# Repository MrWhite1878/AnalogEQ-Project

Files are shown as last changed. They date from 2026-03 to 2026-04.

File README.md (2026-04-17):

# AnalogEQ-Project
This repo serves to document relevant information on the design of an analog audio equalizer, whose goal is to serve as a learning tool and correctional component for my desktop speakers.
<!-- Photo -->
> WARNING: This project is a work in progress.
> Nothing is finalized, and this repo mainly serves to document and catalog my journey.

### Target Specifications
*	RCA audio input/output (adapters included)
*	9VAC Wall Wart power input
* ±18VDC rails powering NE5532 and TL072 op amps
* Smooth knobs for all controls
* High input impedance and low output impedance
* Audio bypass switch
* Input and Output Amplification
* 3rd order butterworth BPF for frequencies outside 20Hz-20kHz
* Sharp (Q = 10) -15dB Notch filter with adjustable target frequency (35-85Hz)
* LF and HF shelving with adjustable gain (±16dB) and proportional break/corner frequency
* 2 fully parametric middle controls: ±15dB gain, 70Hz-1.5kHz range 1 and 700-15kHz range 2, 0.5 < Q < 5
* Diagnostic board LEDs and testing pads

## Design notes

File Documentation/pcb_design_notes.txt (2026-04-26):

I learned KiCad and turned much of the simulation into a KiCad schematic with real components, footprints, MPNs, etc. I did not take any notes during this process, but I will include relevant information here.

Changes to be made: Notch bypass, i/o amplification, diagnostic (smd?) leds, testing pads, replacing/removing 1uF caps (maybe), smd resistors (maybe)

I want the final project to fit cleanly on my desk, in an enclosure. So, I planned for panel mount components (power, audio i/o, knobs). I plan to use JST-XH connectors for everything. I want a separate power board and signal board. I think about the size of notebook paper will do, so I'd like to keep the signal board within 200x100mm^2 and the power board within 100x50mm^2.

Rough estimate 11 pots with 2 switches 30mm center-to-center is about 400mm Panel width or with 2 rows I could get that down to 210*60mm^2 width*height. I like that and I can keep the board 

I decided on a definitive power solution. I do not want to juggle signal design with safety power design, so I will use a wall wart to step down the voltage from the wall to 12VAC. Then, I use a douglas design to double the voltage, rectify it, and pass it through LDOs. This produces extremely clean +-18V rails and avoids me having to worry about complicated power safety issues. The only problem is that with 43mA typ and 100mA max current draw from my op amp, I'll see significant drift from a standard wall wart (rated for about 1A), so I'll use a 9VAC wall wart.

Since this is a stereo circuit, I'll just use each side of the op amp since crosstalk is pretty low. Also thinking of having the component value inside the courtyard and the name outside of the courtyard.

Tried autorouting, kinda ugly. JLPCB has much better pricing than PCBWay based on testing. A little leeway in how I do it, but I should try to keep to standard stuff. TBH 2 Layer is cheaper but 4 layer might make cleaner routing isn;t much more expensive.

I need to find ways to integrate debugging pads and workarounds if something doesn't go well.

Components to buy that won't make it to the BOM:
Power
AC/AC Wall Wart - 77DA-12-09 by Ideal Power Ltd.
Panel Mount Barrel Jack - PJ-009AH by Same Sky
4x 100uF Caps - 

NOTE TO SELF:
You need to document which components you chose and why you chose them. Need to use chassis ground properly for components. Think about enclosure.

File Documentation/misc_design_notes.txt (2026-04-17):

EQ Design Notes

--
I want to design for:
-Bypass Switch for easy comparison/low noise
-Fixed freq HPF/LPF for speaker protection
-Fixed freq LF/HF shelving for broad tone control
-2 Fully parametric middle bands for specific controls
-Sweepable Notch filter for cleaning noise

This exposes me to many different filter designs while being highly functional
--- 
Goal is low resistance, linear, single gang pots. Avoid rotary switches ($5-$10).
Note that compromises made on freq range selection, as changing C in 1/2piRC only shifts the line up and down, not slope freq vs R loglog graphs.
--
Pre-amp not needed because the speakers will handle volume control. 
--
E24 values preferred for components since easier find and I have E24 metal film resistors. E6 caps though. I want metal film resistors default. X5R/X7R caps for decoupling, C0G(NP0) or Polypropylene (>1nF) caps for filters. 1kohm - 4.7kohm seems to be commonplace in audio design, due to balance noise, current, and parasitics. Try to keep cap values below 1u. Otherwise, consider bipolar electrolytic bypassed with PP film.

resistor noise prop. to  sqrt(R)

On decoupling. 100nF close to package across supply rails for NE5532/TL072, not two going to ground to avoid noise.

NE5532P default, solid option at a cheap price (5534 is x2, lm4562 x12). Input current bias on the NE5532 is 200-1000nA, 65-7000pA on the TL072, based on typical at 25C to full range temp. This becomes a problem with bigger resistors (do voltage/current noise calculations), so switch to the TL072 around 20kohm. TL072H might be best bc EMI filters, slew rate, and low power. TL072A/B have tighter input offset voltage. Right now TL072BCP seems to be best bang for buck.
---

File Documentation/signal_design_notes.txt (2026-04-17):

*These are some notes I made to myself while simulating the signal processing circuits in LTspice. I added in a few things I learned during PCB design. Note this was before I made the decision to switch to stereo.*

Sallen-Key vs. MFB
sallen-key is non inverting, but comes back up high freq. sallen-key HPF, MFB LPF.

Sallen-key HPF
Goal is speaker protection and power reduction, not tone shaping. These are corrective devices like the notch. In modern systems, typically used for power reduction of sub bass freq and EMI removal. Don't want audio distortion, so cutoff freq will probably be beyond 20Hz/20kHz. Need butterworth for cleaner rolloff and phase shift isn't significant.

Equal components vs unity gain. Probably unity gain for less distortion.
Unity gain can be scaled with a and b, note this is from Wikipedia not the book.
Maximize C1 and C2, but hard limit at 1u for price reasons. sets R1 and R2.
Optimized for about -1dB at 20Hz, which shouldn't have a noticeable effect on audio. But, it will attenuate low freq signals.

2nd,3rd,4th order. 2nd order is minimal design, typical. 3rd order only uses 1 more cap and 1 more resistor, not expensive. 4th order needs many more parts, and removes the possibility of a combined LPF/HPF. Potentially need to use TL072 on both stages? More parts means more noise. However, higher orders allow for attenuation. 3rd order filter makes sense to me. 1uF PP caps are massive though

MFB LPF

After some hiccups and a lot of math, 3rd order MFB inspired by the 3rd order sallen-key created. Solves all the issues with the sallen-key at HF. But this is best suited with a NE5532, so I may not be able to combine this with the HPF. Perhaps I'll find another stage to combine it with. 

---
Shelving

two cap version better for correction than one cap version. I'm not picky about phase shift, and I think having an appropriate break is more important for LF than HF. Doing double cap configurations on both actually set 3dB freq I was happy with compared to what originally in the book. This is another inverting topology. 10K is not enough noise for me to try to adjust for low impedance issues. Freq shifts with cut/gain which is very nice.

I should consider a switchable version of this with a middle control. Doesnt even have to be fully parametric
---
There's a lot of options for MIddle controls, probably because you can do some summing magic with bandpass filters. As a correctional device, I'm not interested in fixed freq devices. Wein network looks appealing for only using 1 op amp. Considering upgrading to stereo if I can get these designs to work. I'll have to decide how much I value the Q controllability to decide if I want fixed Q, switched Q, or fully variable Q. Compare my current bell to the book version. I like my fully parametric version, but I need to limit the ranges to 100-1k and 1k-10k so I can use smaller pots. Less noise and I can use the NE5532. Nvm main is a gain Q coupled circuit. Slightly modified Self's version (made R4 1K, lower impedance for more gain). This is good but the circuit is so sensitive to the gain/cut pos at the ends of the circuit. No idea how to fix tbh, even a buffer between the pot and r4 didn't do a ton. prolly need a lot of math to fix this.
---
Notch

to get a tunable notch we can use the bridged differentiator in 6.10d. consider the boctor, inverted svf. Adjusted R5 for a sharper Q (10) with less cut (-27dB to -15dB) because it will make it less audible. No phase shift so I can use a bypass switch for when it's off. Shifted caps from douglas to shift freq ranges to 35-85 for better room control 
---
Combined

There will both a bypass switch from input to output and a bypass across the notch. Have to use 2 channel op amps, so 2x NE5532, 4x TL072 = 52mA max draw? According to spice expecting a -90dB SNR

 Considering a new power supply. Added input output buffers. I should also add clipping detectors, LEDs on bypass switches, rubber feet. Reconsider max/min gain / "Master gain control" or "Input attenuator", consider power indicator and enclosure markings. Probably waterslide decals.

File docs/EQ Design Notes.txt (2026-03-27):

EQ Design Notes

--
I want to design for:
-Bypass Switch for easy comparison/low noise
-Fixed freq HPF/LPF for speaker protection
-Fixed freq LF/HF shelving for broad tone control
-2 Fully parametric middle bands for specific controls
-Sweepable Notch filter for cleaning noise

This exposes me to many different filter designs while being highly functional
---
Power: This should only be used when it's near outlets, so it makes sense to have some sort of wall wart, clean up or modify the signal, and make power rails. 15dB is standard max boost. 15dB = 5.62x, so ±15V rails = ±13V output = 2.3V peak input. Seems reasonable. Batteries seems inconvenient and bulk, USB voltage levels considered, but I'm worried about signal integrity, noise, power drain, etc. Not interested in designing power solution right now. Ne5532 draws 8mA max per channel and the TL072B draws 2.5mA max per channel. Likely need a 1W supply.
--
Goal is low resistance, linear, single gang pots. Avoid rotary switches ($5-$10).
Note that compromises made on freq range selection, as changing C in 1/2piRC only shifts the line up and down, not slope freq vs R loglog graphs.
--
Pre-amp not needed because the speakers will handle volume control. 
--
E24 values preferred for components since easier find and I have E24 metal film resistors. E6 caps though. I want metal film resistors default. X5R/X7R caps for decoupling, C0G(NP0) or Polypropylene (>1nF) caps for filters. 1kohm - 4.7kohm seems to be commonplace in audio design, due to balance noise, current, and parasitics. Try to keep cap values below 1u. Otherwise, consider bipolar electrolytic bypassed with PP film.

resistor noise prop. to  sqrt(R)

On decoupling. 100nF close to package across supply rails for NE5532/TL072, not two going to ground to avoid noise.

NE5532P default, solid option at a cheap price (5534 is x2, lm4562 x12). Input current bias on the NE5532 is 200-1000nA, 65-7000pA on the TL072, based on typical at 25C to full range temp. This becomes a problem with bigger resistors (do voltage/current noise calculations), so switch to the TL072 around 20kohm. TL072H might be best bc EMI filters, slew rate, and low power. TL072A/B have tighter input offset voltage. Right now TL072BCP seems to be best bang for buck.
---

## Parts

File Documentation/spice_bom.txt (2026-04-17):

2x NE5532
4x TL072
2x Bypass switch
Power

HPF
3x 1uF
1x 3kΩ
1x 7.5kΩ
1x 51kΩ

LPF
2x 10nF
1x 680pF
1x 1.1kΩ
1x 1.2kΩ
1x 2.7kΩ
1x 3.9kΩ

Notch
3x 220nF
1x 100kΩ
1x 39kΩ
1x 1kΩ
1x 12kΩ
1x 10kΩ pot LOG A
1x 100Ω
1x 10kΩ

Shelf
2x 100nF
2x 15nF
2x 10kΩ pot LIN B
2x 1.8kΩ
3x 1kΩ
1x 12kΩ

Middle1
1x 10nF
1x 47nF
1x 10kΩ pot LIN B
1x 100kΩ pot RLOG C
1x 100kΩ pot RLOG C 2GANG
1x 470Ω
1x 1kΩ
2x 2.2kΩ
4x 4.7kΩ
2x 6.8kΩ
2x 12kΩ
1x 100kΩ

Middle 2 (same, except caps)
1x 1nF
1x 4.7nF

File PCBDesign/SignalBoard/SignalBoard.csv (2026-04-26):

Qty | Value | Manufacturer | MPN | Digikey PN
2 | 680p | YAGEO | CC1206JRNPOYBN681 | 13-CC1206JRNPOYBN681CT-ND
2 | 1n | YAGEO | CC1206JRNPOBBN102 | 13-CC1206JRNPOBBN102CT-ND
2 | 4n7 | YAGEO | CC1206JRNPO0BN472 | 311-4403-1-ND
6 | 10n | YAGEO | CC1206JKNPO0BN103 | 311-4374-1-ND
4 | 15n | KEMET | PHE426DJ5150JR05
2 | 47n | KEMET | PHE426DJ5470JR05
2 | 100n | Vishay Beyschlag/Draloric/BC Components | K104K10X7RF53L2
14 | 100n | Samsung Electro-Mechanics | CL21B104KCFNNNE | 1276-6840-1-ND
4 | 100n | KEMET | PHE426HJ6100JR05
6 | 220n | KEMET | PHE426HA6220JR05
6 | 1u | Panasonic Industry | ECW-FE2W105JA
2 | 100u | Rubycon | 50ZLJ100M8X11.5
4 | 470u | Rubycon | 50ZLJ470M10X20
4 | 10K LIN | Bourns Inc. | PTD902-2215K-B103
1 | 10K LOG | Bourns Inc. | PDB182-K415K-103A1
2 | 47R | YAGEO | RT1206FRE0747RL | 13-RT1206FRE0747RLCT-ND
2 | 100 | YAGEO | RT1206DRD07100RL | 311-2915-1-ND
2 | 100K RLOG | Bourns Inc. | PTD902-2015K-C104
2 | 100K RLOG | Bourns Inc. | PTD904-2015K-C104
4 | 470R | YAGEO | RT1206DRE07470RL | 311-2995-1-ND
12 | 1K | YAGEO | RT1206DRD071KL | 311-2925-1-ND
4 | 1K1 | YAGEO | RT1206FRE071K1L | 13-RT1206FRE071K1LCT-ND
2 | 1K2 | YAGEO | RT1206FRE071K2L | 13-RT1206FRE071K2LCT-ND
4 | 1K8 | YAGEO | RT1206FRE071K8L | 13-RT1206FRE071K8LCT-ND
8 | 2K2 | YAGEO | RT1206DRE072K2L | 311-2984-1-ND
2 | 2K7 | YAGEO | RT1206DRE072K7L | 311-2985-1-ND
2 | 3K | YAGEO | RT1206DRD073KL | 13-RT1206DRD073KLCT-ND
16 | 4K7 | YAGEO | RT1206DRD074K7L | 13-RT1206DRD074K7LCT-ND
8 | 6K8 | YAGEO | RT1206DRD076K8L | 13-RT1206DRD076K8LCT-ND
2 | 7K5 | YAGEO | RT1206FRE077K5L | 13-RT1206FRE077K5LCT-ND
2 | 10K | YAGEO | RT1206DRD0710KL | 311-2916-1-ND
12 | 12K | YAGEO | RT1206DRE0712KL | 311-2960-1-ND
2 | 39K | YAGEO | RT1206DRE0739KL | 311-2991-1-ND
2 | 51K | YAGEO | RT1206DRD0751KL | 13-RT1206DRD0751KLCT-ND
2 | 100K | YAGEO | RT1206DRD07100KL | 311-2914-1-ND
2 | 220K | YAGEO | RT1206FRE07220KL | 13-RT1206FRE07220KLCT-ND
1 | T1A | Bel Fuse Inc. | 0697H1000-02 | 5923-0697H1000-02CT-ND
4 | 1N4004 | onsemi | 1N4004G | 1N4004GOS-ND
1 | ACAC_Wall_Wart | Ideal Power Ltd. | 77DA-12-09
1 | Barrel_Jack_Switch | Tensility International Corp | 54-00127
1 | LM7818_TO220 | onsemi | MC7818CTG
1 | LM7918_TO220 | onsemi | MC7918CTG
5 | NE5532 | Texas Instruments | NE5532P
1 | RCA_IN_L | Kycon, Inc. | KLPX-0848A-2-W
1 | RCA_IN_R | Kycon, Inc. | KLPX-0848A-2-R
1 | RCA_OUT_L | Kycon, Inc. | KLPX-0848A-2-W
1 | RCA_OUT_R | Kycon, Inc. | KLPX-0848A-2-R
2 | SW_4PDT_separate | E-Switch | 1004P1T1B9M7QEH
9 | TL072 | Texas Instruments | TL072BCP

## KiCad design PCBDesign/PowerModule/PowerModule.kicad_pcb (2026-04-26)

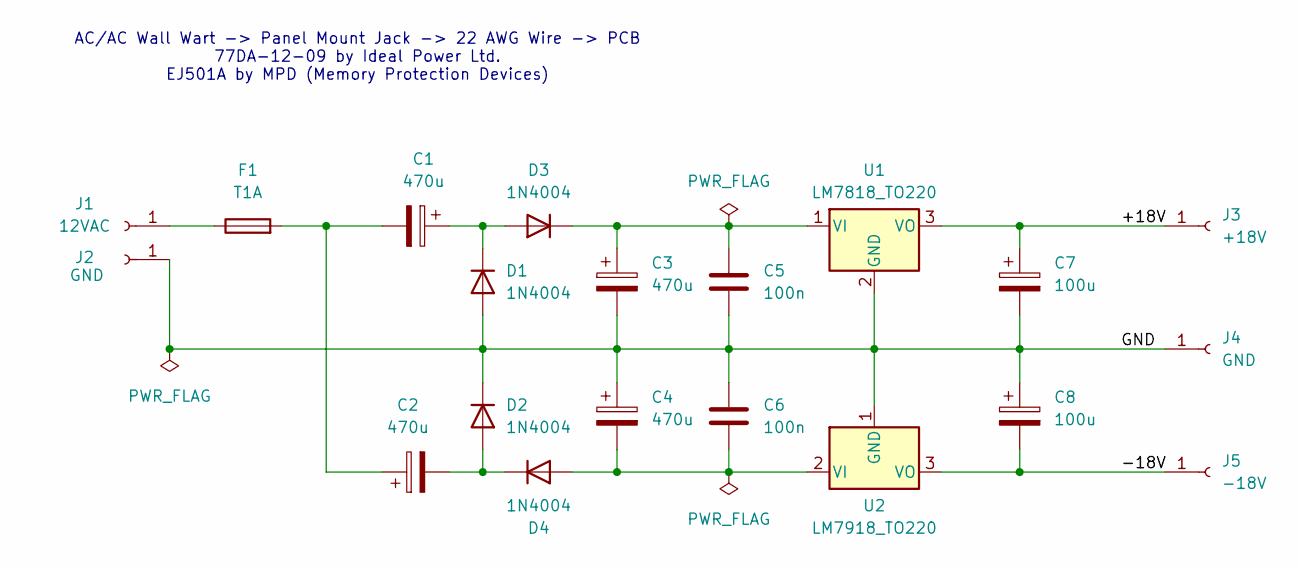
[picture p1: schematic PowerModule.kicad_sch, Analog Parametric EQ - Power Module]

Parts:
C1, C2, C3, C4: 470u; CP_Radial_D10.0mm_P5.00mm; MPN 50ZLJ470M10X20
C5, C6: 100n; C_Disc_D3.8mm_W2.6mm_P2.50mm; MPN K104K10X7RF53L2
C7, C8: 100u; CP_Radial_D8.0mm_P3.50mm; MPN 50ZLJ100M8X11.5
D1, D2, D3, D4: 1N4004; D_DO-41_SOD81_P10.16mm_Horizontal; MPN 1N4004G
F1: T1A; Fuse_BelFuse_0697H; MPN 0697H1000-02
J1: 12VAC; SolderWire-0.5sqmm_1x01_D0.9mm_OD2.1mm_Relief
J2, J4: GND; SolderWire-0.5sqmm_1x01_D0.9mm_OD2.1mm_Relief
J3: +18V; SolderWire-0.5sqmm_1x01_D0.9mm_OD2.1mm_Relief
J5: -18V; SolderWire-0.5sqmm_1x01_D0.9mm_OD2.1mm_Relief
U1: LM7818_TO220; TO-220-3_Vertical; MPN MC7818CTG
U2: LM7918_TO220; TO-220-3_Vertical; MPN MC7918CTG

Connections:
/+18V: C7.1, J3.1 (Pin_1_1), U1.3 (VO)
/-18V: C8.2, J5.1 (Pin_1_1), U2.3 (VO)
/GND: C3.2, C4.1, C5.2, C6.1, C7.2, C8.1, D1.2 (A), D2.1 (K), J2.1 (Pin_1_1), J4.1 (Pin_1_1), U1.2 (GND), U2.1 (GND)
unnamed: C1.2, C2.1, F1.2
unnamed: C1.1, D1.1 (K), D3.2 (A)
unnamed: C2.2, D2.2 (A), D4.1 (K)
unnamed: C3.1, C5.1, D3.1 (K), U1.1 (VI)
unnamed: C4.2, C6.2, D4.2 (A), U2.2 (VI)
unnamed: F1.1, J1.1 (Pin_1_1)

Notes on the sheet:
AC/AC Wall Wart -> Panel Mount Jack -> 22 AWG Wire -> PCB 77DA-12-09 by Ideal Power Ltd. EJ501A by MPD (Memory Protection Devices)

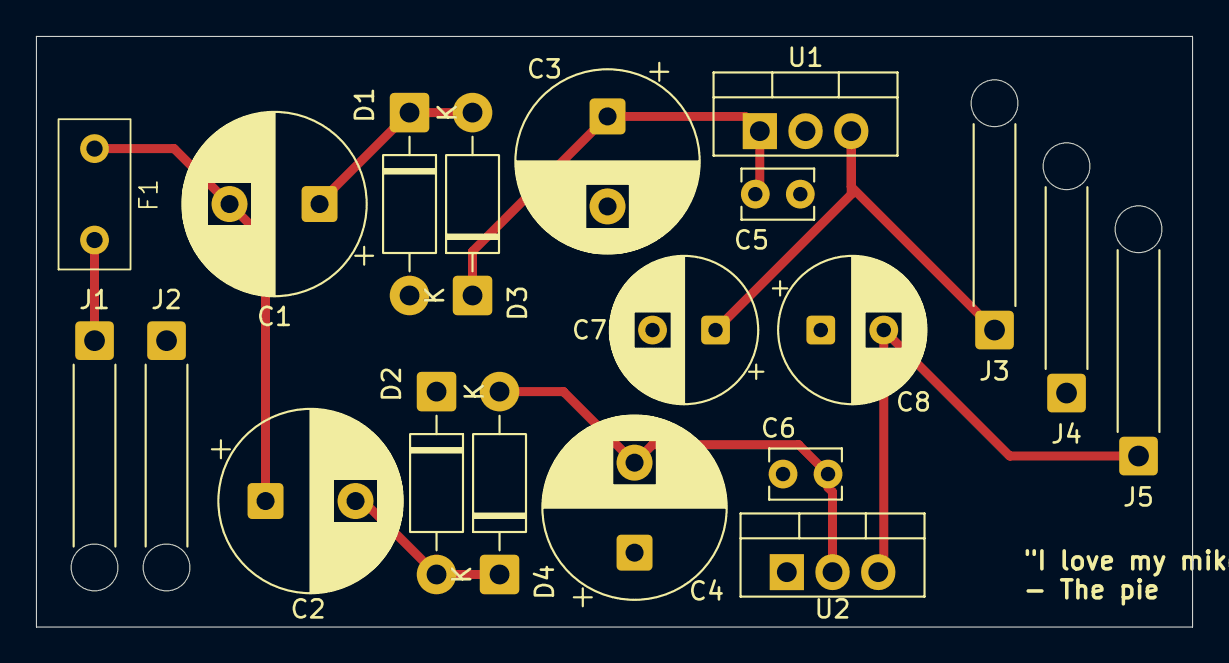
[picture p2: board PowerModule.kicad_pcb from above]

Board: 2 copper layers, 64.2 x 32.8 mm, 20 parts (0 on the bottom side), 9 nets.

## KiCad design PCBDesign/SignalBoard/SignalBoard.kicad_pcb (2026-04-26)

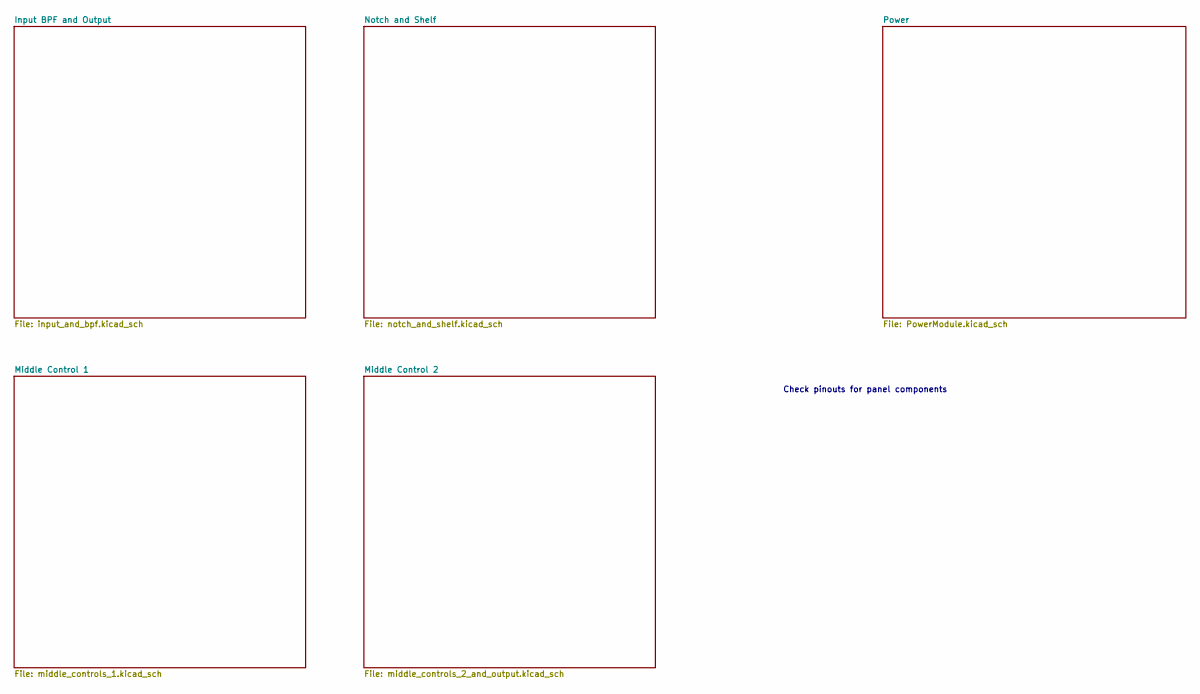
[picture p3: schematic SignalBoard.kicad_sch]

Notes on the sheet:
Check pinouts for panel components

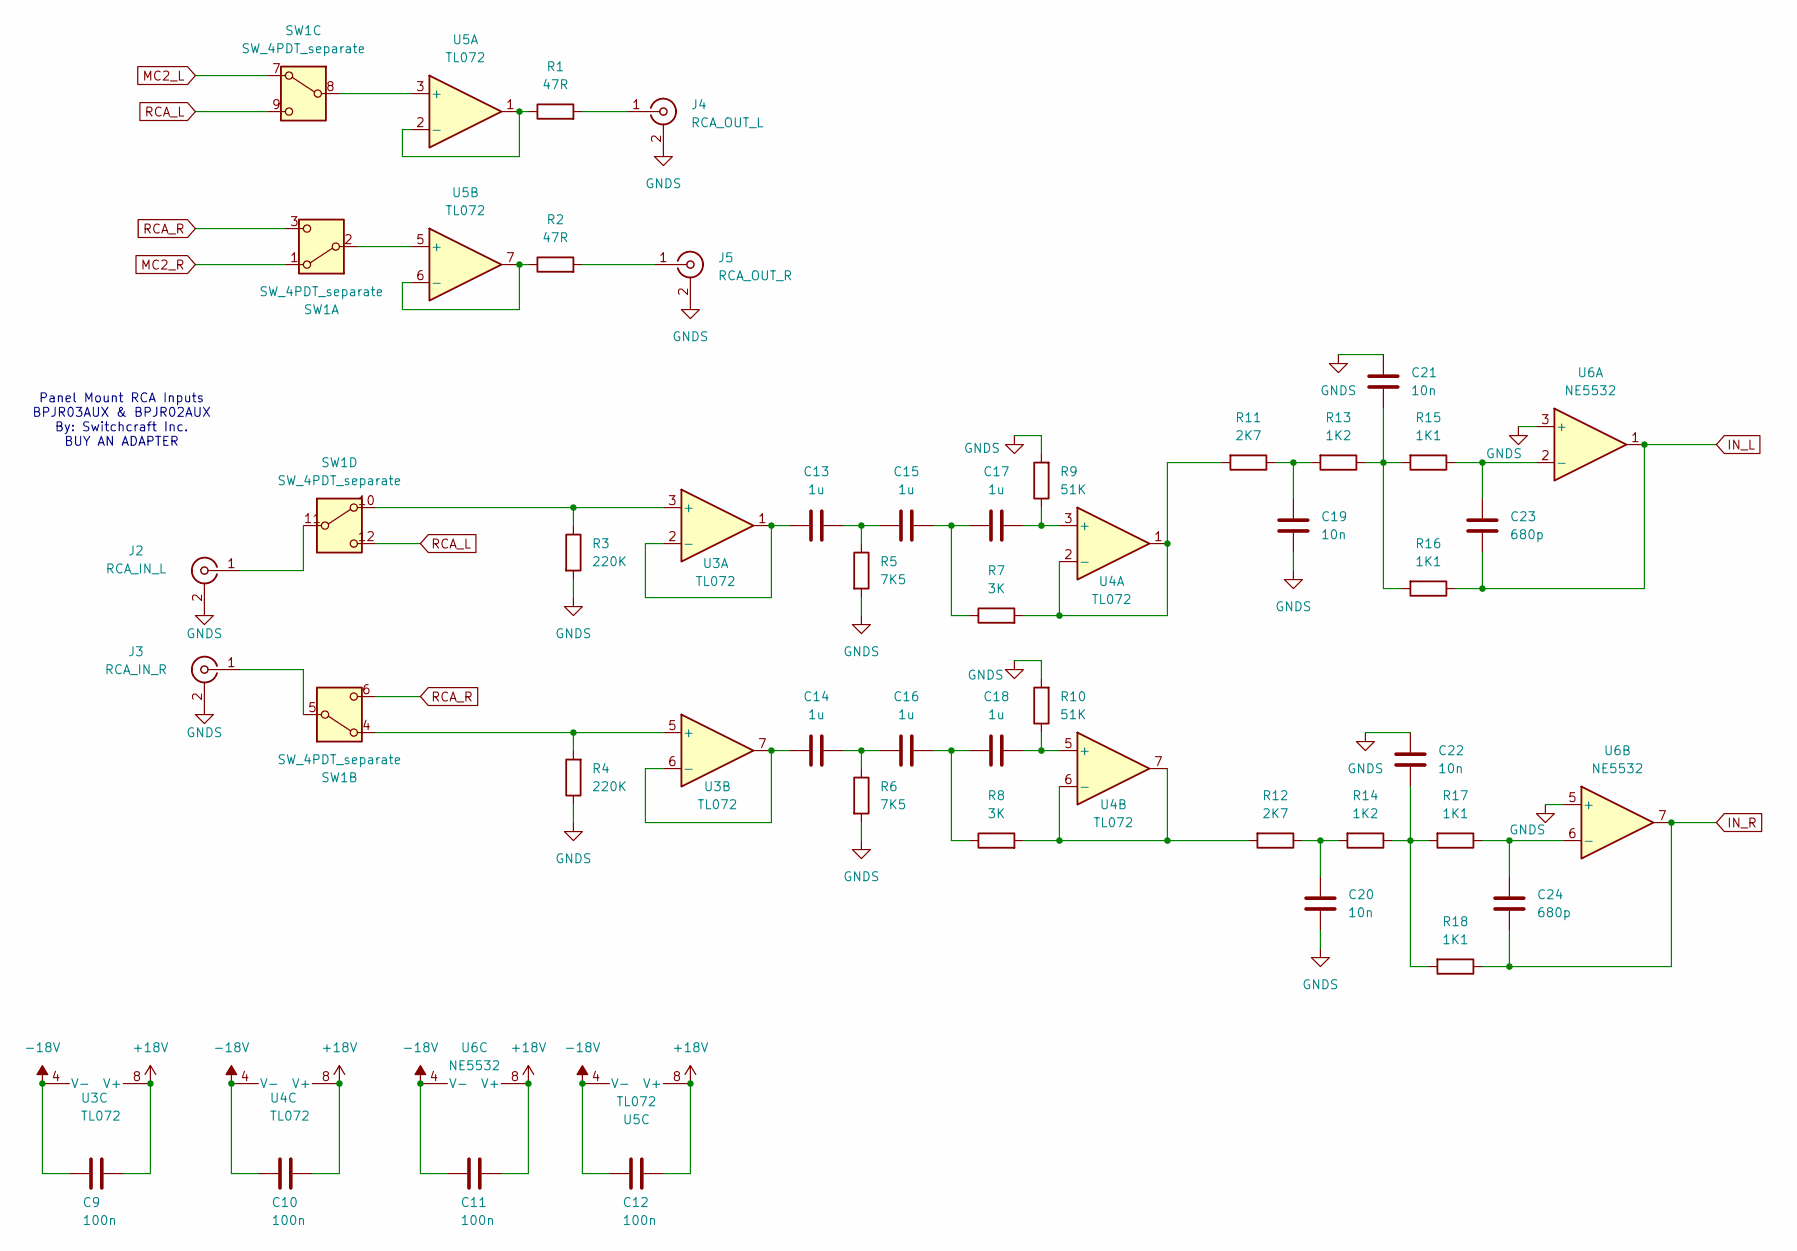
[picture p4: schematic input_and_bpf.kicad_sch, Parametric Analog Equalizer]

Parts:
C9, C10, C11, C12: 100n; C_0805_2012Metric_Pad1.18x1.45mm_HandSolder; MPN CL21B104KCFNNNE; Digikey PN 1276-6840-1-ND
C13, C14, C15, C16, C17, C18: 1u; C_Rect_L18.0mm_W7.0mm_P15.00mm_FKS3_FKP3; MPN ECW-FE2W105JA
C19, C20, C21, C22: 10n; C_1206_3216Metric_Pad1.33x1.80mm_HandSolder; MPN CC1206JKNPO0BN103; Digikey PN 311-4374-1-ND
C23, C24: 680p; C_1206_3216Metric_Pad1.33x1.80mm_HandSolder; MPN CC1206JRNPOYBN681; Digikey PN 13-CC1206JRNPOYBN681CT-ND
J2: RCA_IN_L; KLPX-0848A-2-; MPN KLPX-0848A-2-W
J3: RCA_IN_R; KLPX-0848A-2-; MPN KLPX-0848A-2-R
J4: RCA_OUT_L; KLPX-0848A-2-; MPN KLPX-0848A-2-W
J5: RCA_OUT_R; KLPX-0848A-2-; MPN KLPX-0848A-2-R
R1, R2: 47R; R_1206_3216Metric_Pad1.30x1.75mm_HandSolder; MPN RT1206FRE0747RL; Digikey PN 13-RT1206FRE0747RLCT-ND
R3, R4: 220K; R_1206_3216Metric_Pad1.30x1.75mm_HandSolder; MPN RT1206FRE07220KL; Digikey PN 13-RT1206FRE07220KLCT-ND
R5, R6: 7K5; R_1206_3216Metric_Pad1.30x1.75mm_HandSolder; MPN RT1206FRE077K5L; Digikey PN 13-RT1206FRE077K5LCT-ND
R7, R8: 3K; R_1206_3216Metric_Pad1.30x1.75mm_HandSolder; MPN RT1206DRD073KL; Digikey PN 13-RT1206DRD073KLCT-ND
R9, R10: 51K; R_1206_3216Metric_Pad1.30x1.75mm_HandSolder; MPN RT1206DRD0751KL; Digikey PN 13-RT1206DRD0751KLCT-ND
R11, R12: 2K7; R_1206_3216Metric_Pad1.30x1.75mm_HandSolder; MPN RT1206DRE072K7L; Digikey PN 311-2985-1-ND
R13, R14: 1K2; R_1206_3216Metric_Pad1.30x1.75mm_HandSolder; MPN RT1206FRE071K2L; Digikey PN 13-RT1206FRE071K2LCT-ND
R15, R16, R17, R18: 1K1; R_1206_3216Metric_Pad1.30x1.75mm_HandSolder; MPN RT1206FRE071K1L; Digikey PN 13-RT1206FRE071K1LCT-ND
SW1: SW_4PDT_separate; 1004P1T1B9M7QEH; MPN 1004P1T1B9M7QEH
U3, U4, U5: TL072; DIP-8_W7.62mm_LongPads; MPN TL072BCP
U6: NE5532; DIP-8_W7.62mm_LongPads; MPN NE5532P

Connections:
+18V: C9.1, C10.1, C11.1, C12.1, U3.8 (V+), U4.8 (V+), U5.8 (V+), U6.8 (V+); also elsewhere on the board
-18V: C9.2, C10.2, C11.2, C12.2, U3.4 (V-), U4.4 (V-), U5.4 (V-), U6.4 (V-); also elsewhere on the board
GNDS: C19.2, C20.2, C21.1, C22.1, J2.2 (Ext), J3.2 (Ext), J4.2 (Ext), J5.2 (Ext), R3.2, R4.1, R5.2, R6.2, R9.2, R10.2, U6.3 (+), U6.5 (+); also elsewhere on the board
IN_L: C23.2, R16.1, U6.1; also elsewhere on the board
IN_R: C24.2, R18.1, U6.7; also elsewhere on the board
MC2_L: SW1.7 (A); also elsewhere on the board
MC2_R: SW1.1 (A); also elsewhere on the board
unnamed: C13.2, C15.1, R5.1
unnamed: C14.2, C16.1, R6.1
unnamed: C15.2, C17.1, R7.1
unnamed: C16.2, C18.1, R8.1
unnamed: C19.1, R11.1, R13.2
unnamed: C20.1, R12.1, R14.2
unnamed: C21.2, R13.1, R15.2, R16.2
unnamed: C22.2, R14.1, R17.2, R18.2
unnamed: J2.1 (In), SW1.11 (B)
unnamed: J3.1 (In), SW1.5 (B)
unnamed: J4.1 (In), R1.2
unnamed: J5.1 (In), R2.2
unnamed: SW1.2 (B), U5.5 (+)
unnamed: R4.2, SW1.4 (A), U3.5 (+)
unnamed: SW1.8 (B), U5.3 (+)
unnamed: R3.1, SW1.10 (A), U3.3 (+)
unnamed: C13.1, U3.1, U3.2 (-)
unnamed: C14.1, U3.6 (-), U3.7
unnamed: C17.2, R9.1, U4.3 (+)
unnamed: R7.2, R11.2, U4.1, U4.2 (-)
unnamed: C18.2, R10.1, U4.5 (+)
unnamed: R8.2, R12.2, U4.6 (-), U4.7
unnamed: R1.1, U5.1, U5.2 (-)
unnamed: R2.1, U5.6 (-), U5.7
unnamed: C23.1, R15.1, U6.2 (-)
unnamed: C24.1, R17.1, U6.6 (-)
RCA_L: SW1.9 (C), SW1.12 (C)
RCA_R: SW1.3 (C), SW1.6 (C)

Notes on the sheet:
Panel Mount RCA Inputs BPJR03AUX & BPJR02AUX By: Switchcraft Inc. BUY AN ADAPTER

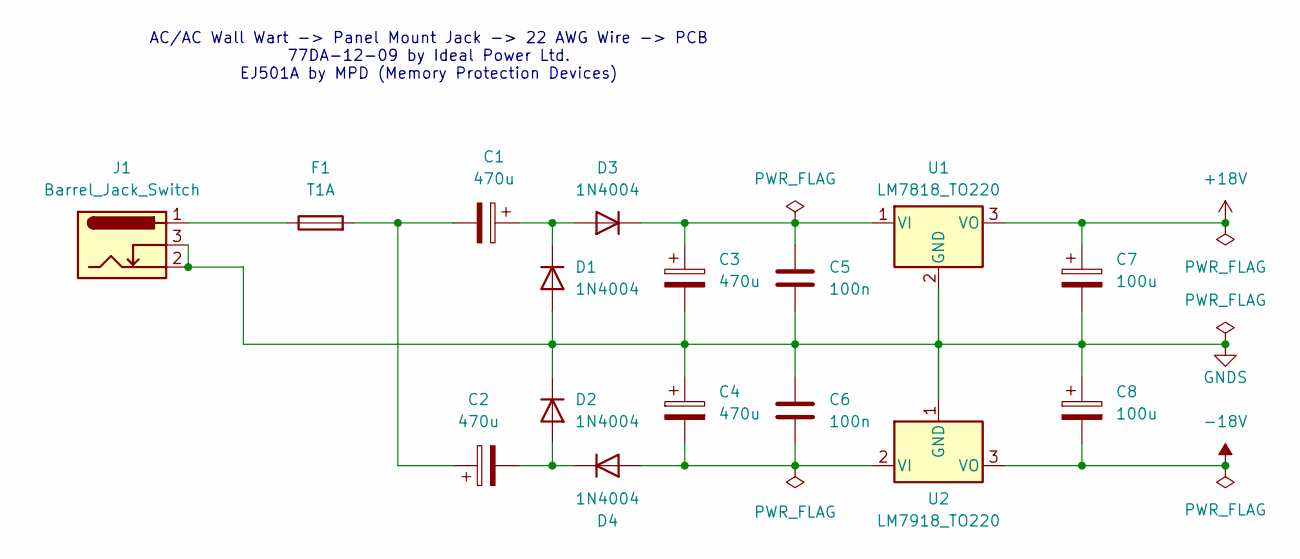
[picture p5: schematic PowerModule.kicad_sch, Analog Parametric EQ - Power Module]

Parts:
C1, C2, C3, C4: 470u; CP_Radial_D10.0mm_P5.00mm; MPN 50ZLJ470M10X20
C5, C6: 100n; C_Disc_D3.8mm_W2.6mm_P2.50mm; MPN K104K10X7RF53L2
C7, C8: 100u; CP_Radial_D8.0mm_P3.50mm; MPN 50ZLJ100M8X11.5
D1, D2, D3, D4: 1N4004; D_DO-41_SOD81_P10.16mm_Horizontal; MPN 1N4004G; Digikey PN 1N4004GOS-ND
F1: T1A; Fuse_BelFuse_0697H; MPN 0697H1000-02; Digikey PN 5923-0697H1000-02CT-ND
J1: Barrel_Jack_Switch; 54-00127; MPN 54-00127
U1: LM7818_TO220; TO-220-3_Vertical; MPN MC7818CTG
U2: LM7918_TO220; TO-220-3_Vertical; MPN MC7918CTG

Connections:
+18V: C7.1, U1.3 (VO); also elsewhere on the board
-18V: C8.2, U2.3 (VO); also elsewhere on the board
GNDS: C3.2, C4.1, C5.2, C6.1, C7.2, C8.1, D1.2 (A), D2.1 (K), J1.2, J1.3, U1.2 (GND), U2.1 (GND); also elsewhere on the board
unnamed: C1.2, C2.1, F1.2
unnamed: C1.1, D1.1 (K), D3.2 (A)
unnamed: C2.2, D2.2 (A), D4.1 (K)
unnamed: C3.1, C5.1, D3.1 (K), U1.1 (VI)
unnamed: C4.2, C6.2, D4.2 (A), U2.2 (VI)
unnamed: F1.1, J1.1

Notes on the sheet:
AC/AC Wall Wart -> Panel Mount Jack -> 22 AWG Wire -> PCB 77DA-12-09 by Ideal Power Ltd. EJ501A by MPD (Memory Protection Devices)

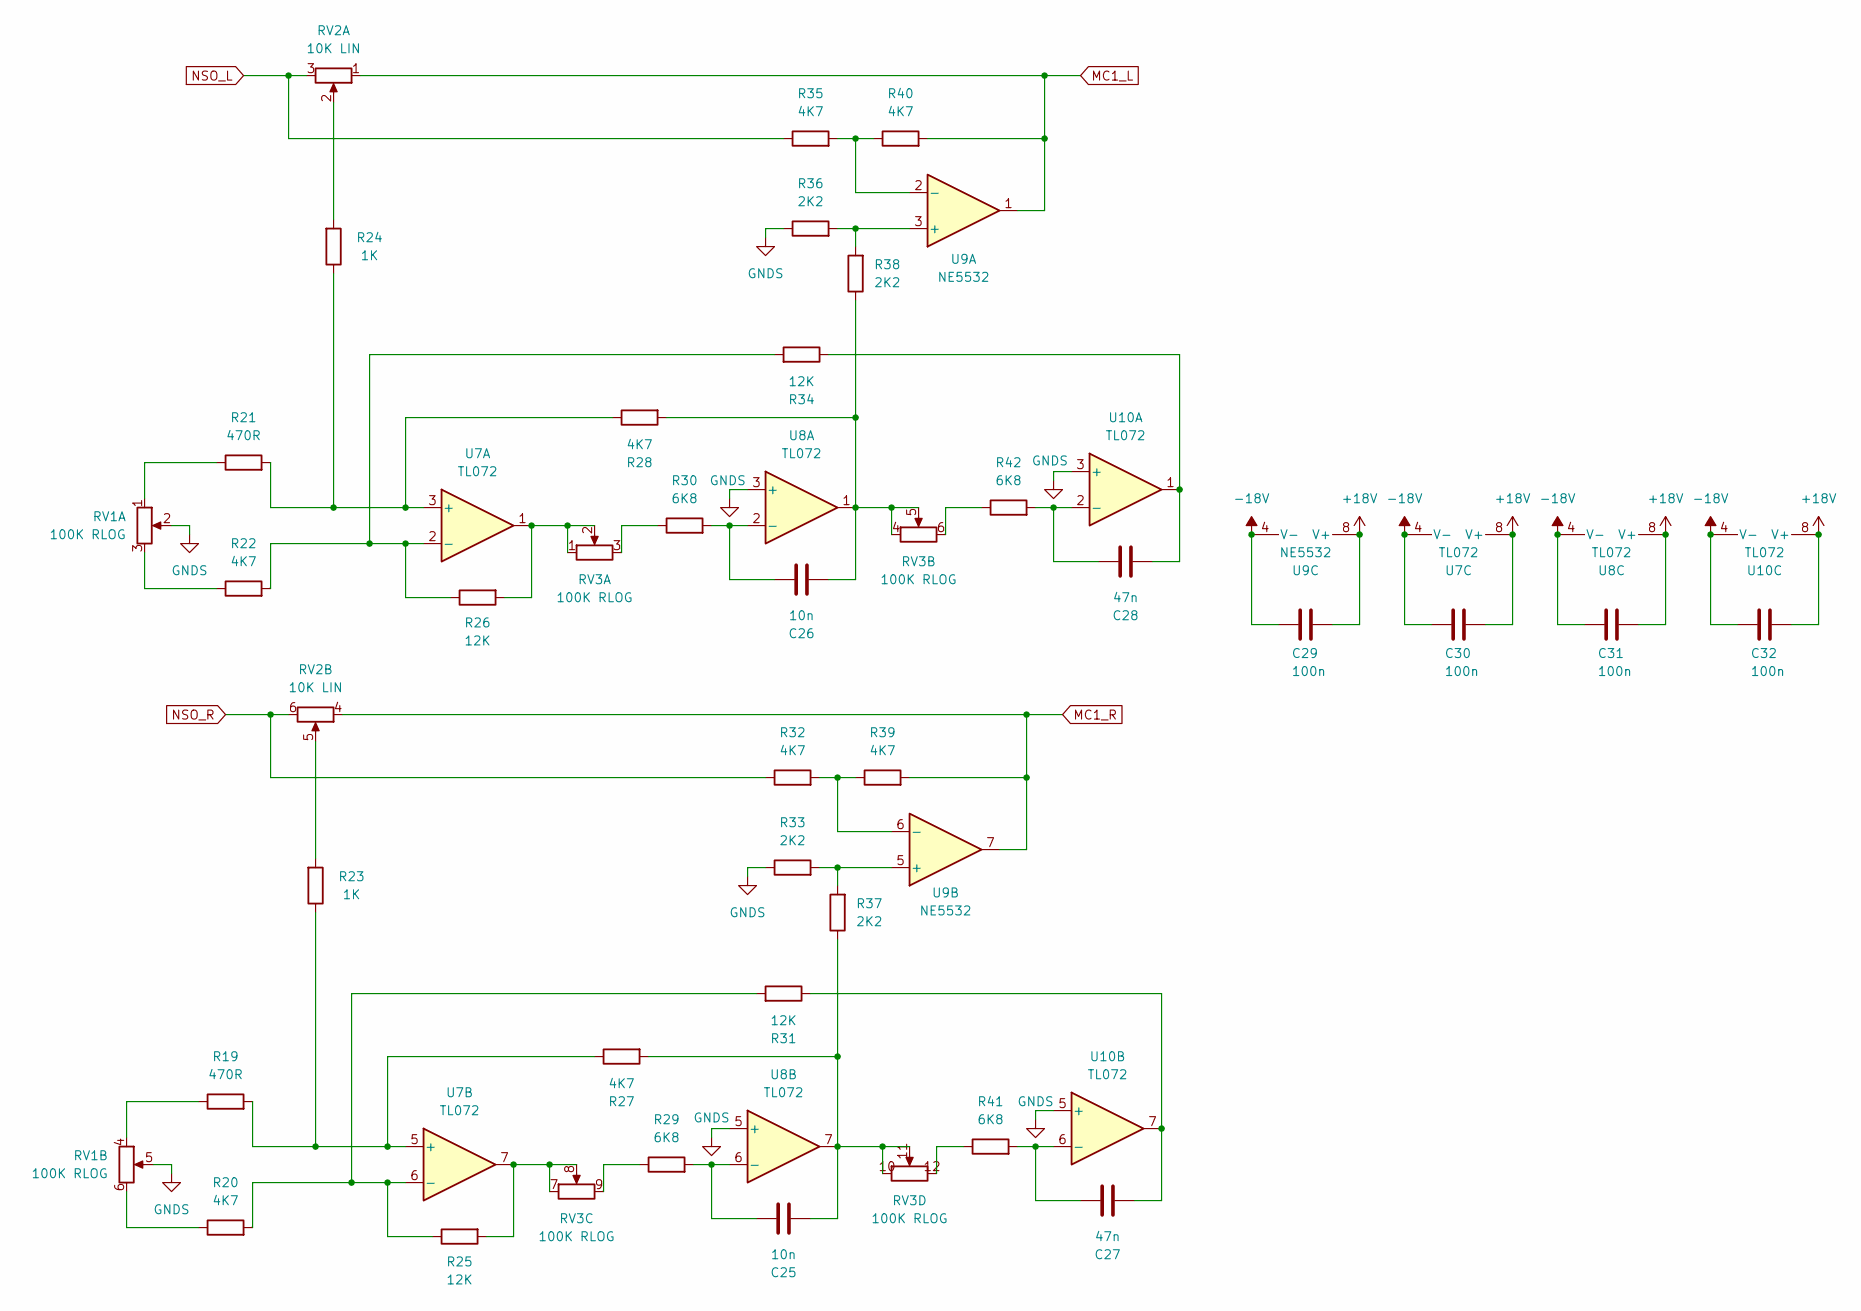
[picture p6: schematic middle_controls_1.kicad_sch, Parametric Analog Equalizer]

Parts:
C25, C26: 10n; C_1206_3216Metric_Pad1.33x1.80mm_HandSolder; MPN CC1206JKNPO0BN103; Digikey PN 311-4374-1-ND
C27, C28: 47n; C_Rect_L7.2mm_W3.5mm_P5.00mm_FKS2_FKP2_MKS2_MKP2; MPN PHE426DJ5470JR05
C29, C30, C31, C32: 100n; C_0805_2012Metric_Pad1.18x1.45mm_HandSolder; MPN CL21B104KCFNNNE; Digikey PN 1276-6840-1-ND
R19, R21: 470R; R_1206_3216Metric_Pad1.30x1.75mm_HandSolder; MPN RT1206DRE07470RL; Digikey PN 311-2995-1-ND
R20, R22, R27, R28, R32, R35, R39, R40: 4K7; R_1206_3216Metric_Pad1.30x1.75mm_HandSolder; MPN RT1206DRD074K7L; Digikey PN 13-RT1206DRD074K7LCT-ND
R23, R24: 1K; R_1206_3216Metric_Pad1.30x1.75mm_HandSolder; MPN RT1206DRD071KL; Digikey PN 311-2925-1-ND
R25, R26, R31, R34: 12K; R_1206_3216Metric_Pad1.30x1.75mm_HandSolder; MPN RT1206DRE0712KL; Digikey PN 311-2960-1-ND
R29, R30, R41, R42: 6K8; R_1206_3216Metric_Pad1.30x1.75mm_HandSolder; MPN RT1206DRD076K8L; Digikey PN 13-RT1206DRD076K8LCT-ND
R33, R36, R37, R38: 2K2; R_1206_3216Metric_Pad1.30x1.75mm_HandSolder; MPN RT1206DRE072K2L; Digikey PN 311-2984-1-ND
RV1: 100K RLOG; PTD902-2215K-B103; MPN PTD902-2015K-C104
RV2: 10K LIN; PTD902-2215K-B103; MPN PTD902-2215K-B103
RV3: 100K RLOG; PTD904-2015K-C104; MPN PTD904-2015K-C104
U7, U8, U10: TL072; DIP-8_W7.62mm_LongPads; MPN TL072BCP
U9: NE5532; DIP-8_W7.62mm_LongPads; MPN NE5532P

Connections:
+18V: C29.1, C30.1, C31.1, C32.1, U7.8 (V+), U8.8 (V+), U9.8 (V+), U10.8 (V+); also elsewhere on the board
-18V: C29.2, C30.2, C31.2, C32.2, U7.4 (V-), U8.4 (V-), U9.4 (V-), U10.4 (V-); also elsewhere on the board
GNDS: R33.1, R36.1, RV1.2, RV1.5, U8.3 (+), U8.5 (+), U10.3 (+), U10.5 (+); also elsewhere on the board
MC1_L: R40.2, RV2.1, U9.1; also elsewhere on the board
MC1_R: R39.2, RV2.4, U9.7; also elsewhere on the board
NSO_L: R35.1, RV2.3; also elsewhere on the board
NSO_R: R32.1, RV2.6; also elsewhere on the board
unnamed: C25.2, R27.2, R37.1, RV3.10, RV3.11, U8.7
unnamed: C26.2, R28.2, R38.1, RV3.4, RV3.5, U8.1
unnamed: C27.2, R31.1, U10.7
unnamed: C28.2, R34.1, U10.1
unnamed: R19.1, RV1.4
unnamed: R20.1, RV1.6
unnamed: R21.1, RV1.1
unnamed: R22.1, RV1.3
unnamed: R23.2, RV2.5
unnamed: R24.2, RV2.2
unnamed: R25.2, RV3.7, RV3.8, U7.7
unnamed: R26.2, RV3.1, RV3.2, U7.1
unnamed: R29.1, RV3.9
unnamed: R30.1, RV3.3
unnamed: R41.1, RV3.12
unnamed: R42.1, RV3.6
unnamed: R21.2, R24.1, R28.1, U7.3 (+)
unnamed: R22.2, R26.1, R34.2, U7.2 (-)
unnamed: R19.2, R23.1, R27.1, U7.5 (+)
unnamed: R20.2, R25.1, R31.2, U7.6 (-)
unnamed: C26.1, R30.2, U8.2 (-)
unnamed: C25.1, R29.2, U8.6 (-)
unnamed: R36.2, R38.2, U9.3 (+)
unnamed: R35.2, R40.1, U9.2 (-)
unnamed: R33.2, R37.2, U9.5 (+)
unnamed: R32.2, R39.1, U9.6 (-)
unnamed: C28.1, R42.2, U10.2 (-)
unnamed: C27.1, R41.2, U10.6 (-)

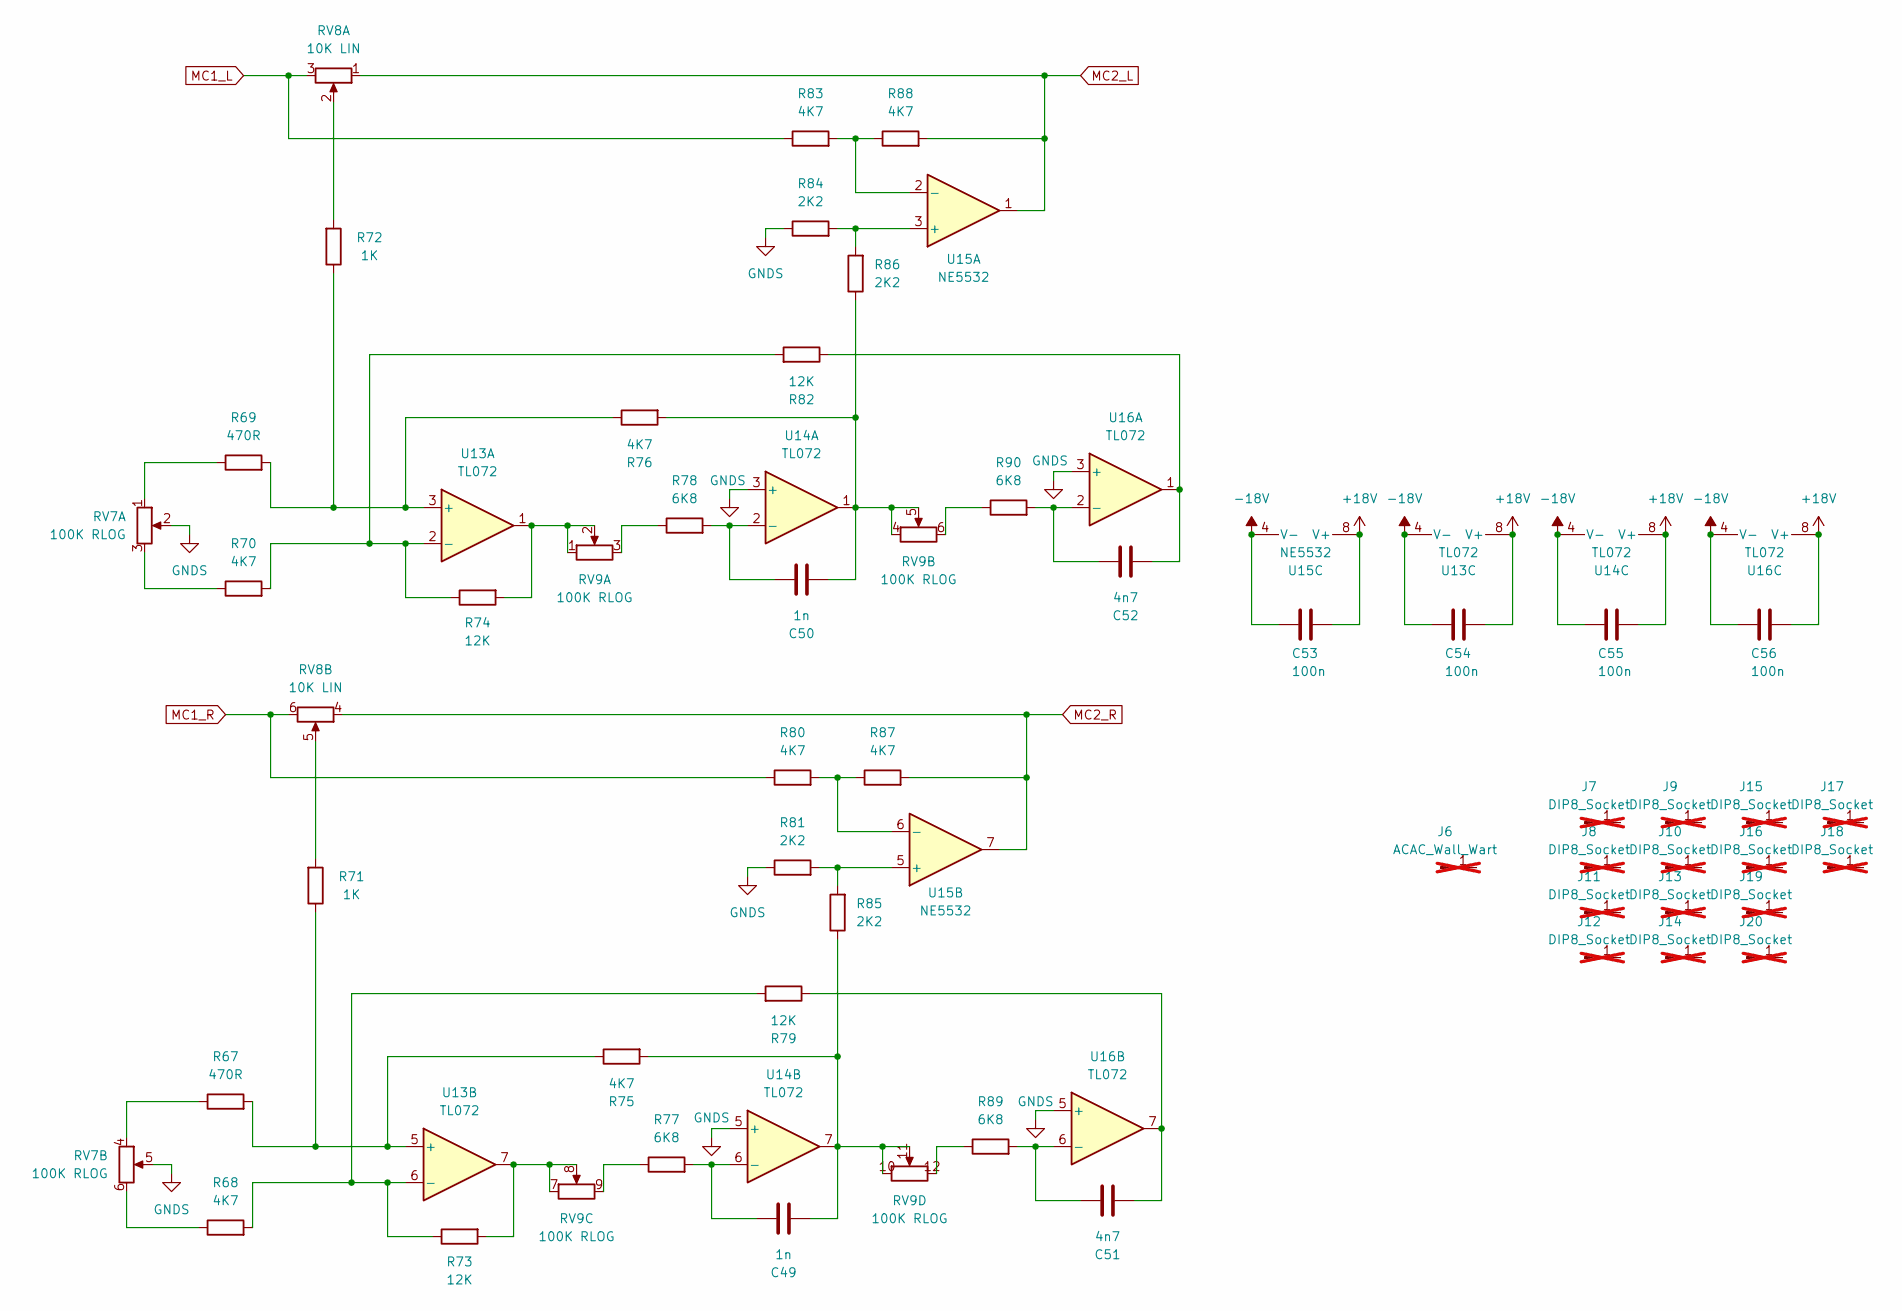
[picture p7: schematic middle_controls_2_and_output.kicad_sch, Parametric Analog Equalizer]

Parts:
C49, C50: 1n; C_1206_3216Metric_Pad1.33x1.80mm_HandSolder; MPN CC1206JRNPOBBN102; Digikey PN 13-CC1206JRNPOBBN102CT-ND
C51, C52: 4n7; C_1206_3216Metric_Pad1.33x1.80mm_HandSolder; MPN CC1206JRNPO0BN472; Digikey PN 311-4403-1-ND
C53, C54, C55, C56: 100n; C_0805_2012Metric_Pad1.18x1.45mm_HandSolder; MPN CL21B104KCFNNNE; Digikey PN 1276-6840-1-ND
J6: ACAC_Wall_Wart; MPN 77DA-12-09; not fitted
J7, J8, J9, J10, J11, J12, J13, J14, J15, J16, J17, J18, J19, J20: DIP8_Socket; MPN ICS-308-T; Digikey PN 2057-ICS-308-T-ND; not fitted
R67, R69: 470R; R_1206_3216Metric_Pad1.30x1.75mm_HandSolder; MPN RT1206DRE07470RL; Digikey PN 311-2995-1-ND
R68, R70, R75, R76, R80, R83, R87, R88: 4K7; R_1206_3216Metric_Pad1.30x1.75mm_HandSolder; MPN RT1206DRD074K7L; Digikey PN 13-RT1206DRD074K7LCT-ND
R71, R72: 1K; R_1206_3216Metric_Pad1.30x1.75mm_HandSolder; MPN RT1206DRD071KL; Digikey PN 311-2925-1-ND
R73, R74, R79, R82: 12K; R_1206_3216Metric_Pad1.30x1.75mm_HandSolder; MPN RT1206DRE0712KL; Digikey PN 311-2960-1-ND
R77, R78, R89, R90: 6K8; R_1206_3216Metric_Pad1.30x1.75mm_HandSolder; MPN RT1206DRD076K8L; Digikey PN 13-RT1206DRD076K8LCT-ND
R81, R84, R85, R86: 2K2; R_1206_3216Metric_Pad1.30x1.75mm_HandSolder; MPN RT1206DRE072K2L; Digikey PN 311-2984-1-ND
RV7: 100K RLOG; PTD902-2215K-B103; MPN PTD902-2015K-C104
RV8: 10K LIN; PTD902-2215K-B103; MPN PTD902-2215K-B103
RV9: 100K RLOG; PTD904-2015K-C104; MPN PTD904-2015K-C104
U13, U14, U16: TL072; DIP-8_W7.62mm_LongPads; MPN TL072BCP
U15: NE5532; DIP-8_W7.62mm_LongPads; MPN NE5532P

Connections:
+18V: C53.1, C54.1, C55.1, C56.1, U13.8 (V+), U14.8 (V+), U15.8 (V+), U16.8 (V+); also elsewhere on the board
-18V: C53.2, C54.2, C55.2, C56.2, U13.4 (V-), U14.4 (V-), U15.4 (V-), U16.4 (V-); also elsewhere on the board
GNDS: R81.1, R84.1, RV7.2, RV7.5, U14.3 (+), U14.5 (+), U16.3 (+), U16.5 (+); also elsewhere on the board
MC1_L: R83.1, RV8.3; also elsewhere on the board
MC1_R: R80.1, RV8.6; also elsewhere on the board
MC2_L: R88.2, RV8.1, U15.1; also elsewhere on the board
MC2_R: R87.2, RV8.4, U15.7; also elsewhere on the board
unnamed: C49.2, R75.2, R85.1, RV9.10, RV9.11, U14.7
unnamed: C50.2, R76.2, R86.1, RV9.4, RV9.5, U14.1
unnamed: C51.2, R79.1, U16.7
unnamed: C52.2, R82.1, U16.1
unnamed: R67.1, RV7.4
unnamed: R68.1, RV7.6
unnamed: R69.1, RV7.1
unnamed: R70.1, RV7.3
unnamed: R71.2, RV8.5
unnamed: R72.2, RV8.2
unnamed: R73.2, RV9.7, RV9.8, U13.7
unnamed: R74.2, RV9.1, RV9.2, U13.1
unnamed: R77.1, RV9.9
unnamed: R78.1, RV9.3
unnamed: R89.1, RV9.12
unnamed: R90.1, RV9.6
unnamed: R69.2, R72.1, R76.1, U13.3 (+)
unnamed: R70.2, R74.1, R82.2, U13.2 (-)
unnamed: R67.2, R71.1, R75.1, U13.5 (+)
unnamed: R68.2, R73.1, R79.2, U13.6 (-)
unnamed: C50.1, R78.2, U14.2 (-)
unnamed: C49.1, R77.2, U14.6 (-)
unnamed: R84.2, R86.2, U15.3 (+)
unnamed: R83.2, R88.1, U15.2 (-)
unnamed: R81.2, R85.2, U15.5 (+)
unnamed: R80.2, R87.1, U15.6 (-)
unnamed: C52.1, R90.2, U16.2 (-)
unnamed: C51.1, R89.2, U16.6 (-)

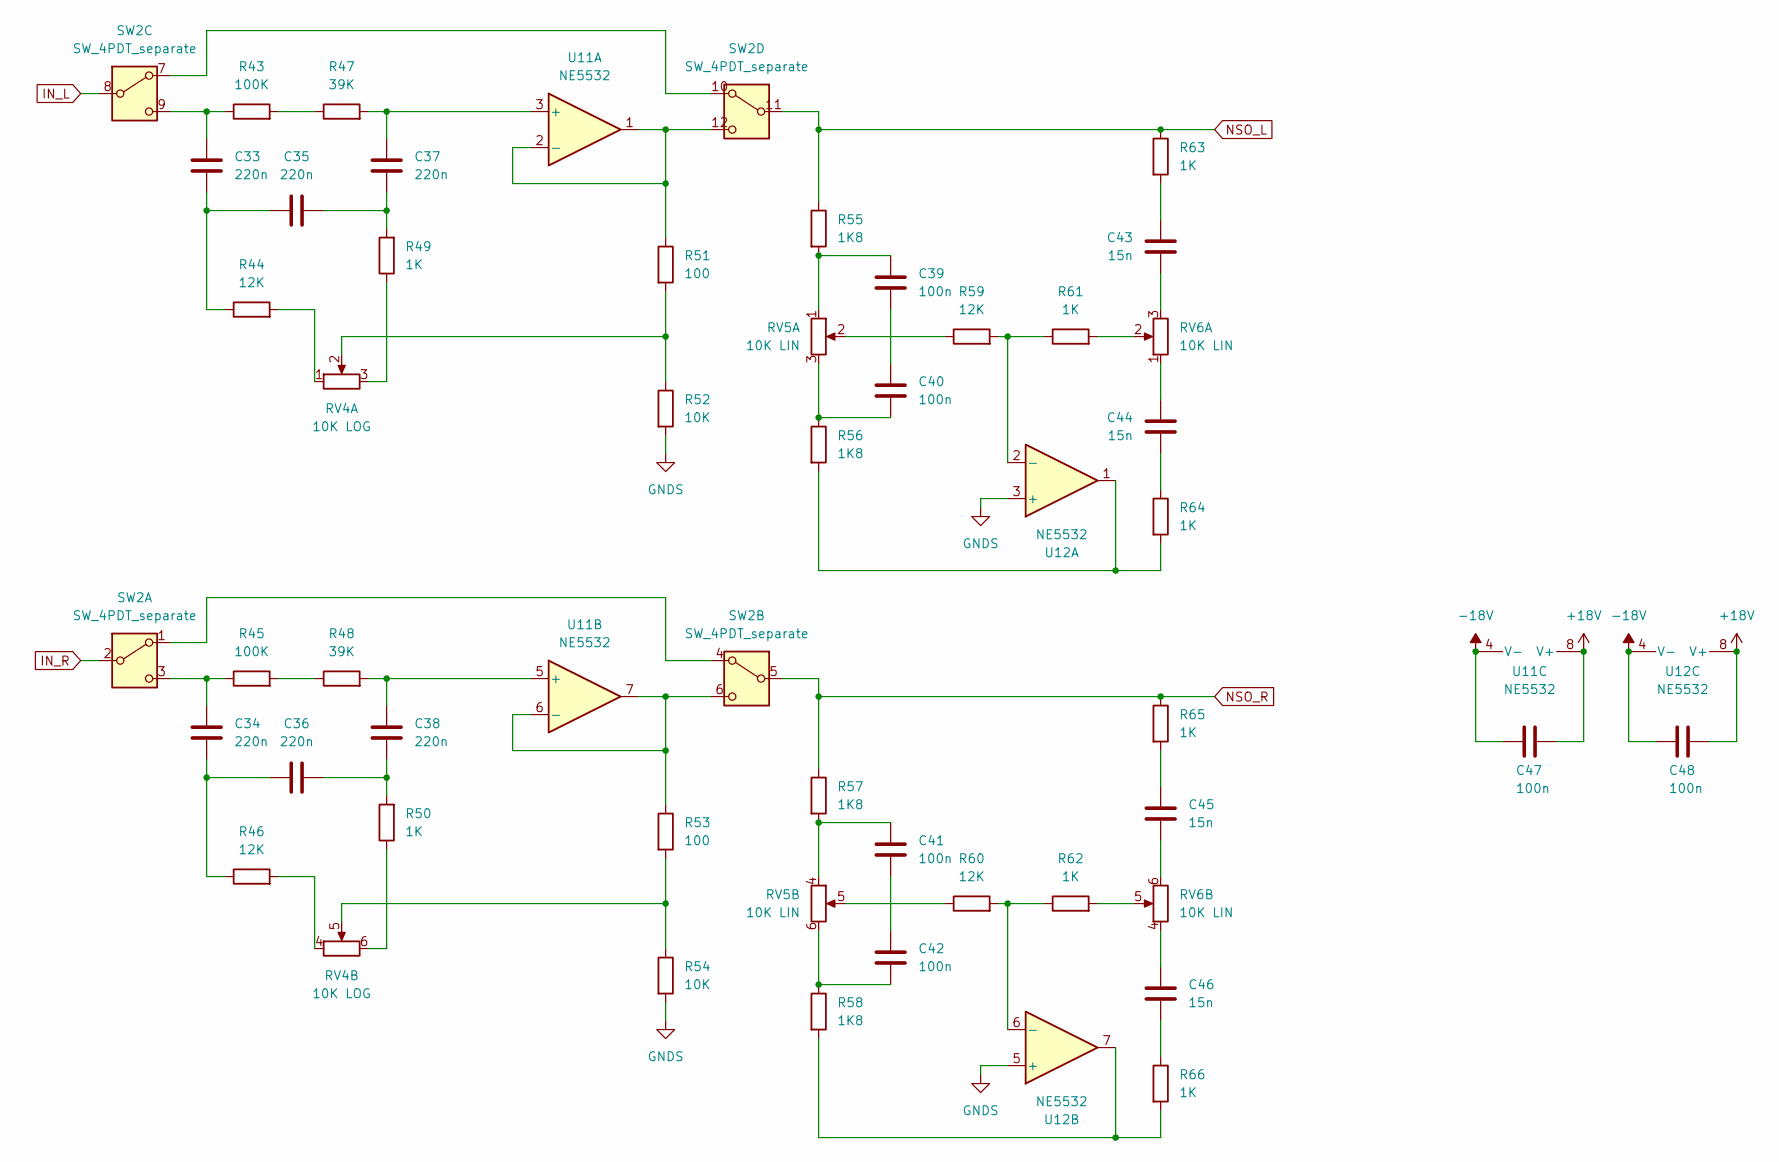
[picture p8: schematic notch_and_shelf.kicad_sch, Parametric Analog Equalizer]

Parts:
C33, C34, C35, C36, C37, C38: 220n; C_Rect_L13.0mm_W6.0mm_P10.00mm_FKS3_FKP3_MKS4; MPN PHE426HA6220JR05
C39, C40, C41, C42: 100n; C_Rect_L7.2mm_W6.0mm_P5.00mm; MPN PHE426HJ6100JR05
C43, C44, C45, C46: 15n; C_Rect_L7.2mm_W2.5mm_P5.00mm_FKS2_FKP2_MKS2_MKP2; MPN PHE426DJ5150JR05
C47, C48: 100n; C_0805_2012Metric_Pad1.18x1.45mm_HandSolder; MPN CL21B104KCFNNNE; Digikey PN 1276-6840-1-ND
R43, R45: 100K; R_1206_3216Metric_Pad1.30x1.75mm_HandSolder; MPN RT1206DRD07100KL; Digikey PN 311-2914-1-ND
R44, R46, R59, R60: 12K; R_1206_3216Metric_Pad1.30x1.75mm_HandSolder; MPN RT1206DRE0712KL; Digikey PN 311-2960-1-ND
R47, R48: 39K; R_1206_3216Metric_Pad1.30x1.75mm_HandSolder; MPN RT1206DRE0739KL; Digikey PN 311-2991-1-ND
R49, R50, R61, R62, R63, R64, R65, R66: 1K; R_1206_3216Metric_Pad1.30x1.75mm_HandSolder; MPN RT1206DRD071KL; Digikey PN 311-2925-1-ND
R51, R53: 100; R_1206_3216Metric_Pad1.30x1.75mm_HandSolder; MPN RT1206DRD07100RL; Digikey PN 311-2915-1-ND
R52, R54: 10K; R_1206_3216Metric_Pad1.30x1.75mm_HandSolder; MPN RT1206DRD0710KL; Digikey PN 311-2916-1-ND
R55, R56, R57, R58: 1K8; R_1206_3216Metric_Pad1.30x1.75mm_HandSolder; MPN RT1206FRE071K8L; Digikey PN 13-RT1206FRE071K8LCT-ND
RV4: 10K LOG; PDB182-K415K-103A1; MPN PDB182-K415K-103A1
RV5, RV6: 10K LIN; PTD902-2215K-B103; MPN PTD902-2215K-B103
SW2: SW_4PDT_separate; 1004P1T1B9M7QEH; MPN 1004P1T1B9M7QEH
U11, U12: NE5532; DIP-8_W7.62mm_LongPads; MPN NE5532P

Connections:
+18V: C47.1, C48.1, U11.8 (V+), U12.8 (V+); also elsewhere on the board
-18V: C47.2, C48.2, U11.4 (V-), U12.4 (V-); also elsewhere on the board
GNDS: R52.2, R54.2, U12.3 (+), U12.5 (+); also elsewhere on the board
IN_L: SW2.8 (B); also elsewhere on the board
IN_R: SW2.2 (B); also elsewhere on the board
NSO_L: R55.1, R63.1, SW2.11 (B); also elsewhere on the board
NSO_R: R57.1, R65.1, SW2.5 (B); also elsewhere on the board
unnamed: C33.2, C35.1, R44.1
unnamed: C34.2, C36.1, R46.1
unnamed: C35.2, C37.2, R49.2
unnamed: C36.2, C38.2, R50.2
unnamed: C39.1, R55.2, RV5.1
unnamed: C39.2, C40.1
unnamed: C40.2, R56.1, RV5.3
unnamed: C41.1, R57.2, RV5.4
unnamed: C41.2, C42.1
unnamed: C42.2, R58.1, RV5.6
unnamed: C43.1, R63.2
unnamed: C43.2, RV6.3
unnamed: C44.1, RV6.1
unnamed: C44.2, R64.1
unnamed: C45.1, R65.2
unnamed: C45.2, RV6.6
unnamed: C46.1, RV6.4
unnamed: C46.2, R66.1
unnamed: R43.2, R47.1
unnamed: R44.2, RV4.1
unnamed: R45.2, R48.1
unnamed: R46.2, RV4.4
unnamed: R49.1, RV4.3
unnamed: R50.1, RV4.6
unnamed: R51.2, R52.1, RV4.2
unnamed: R53.2, R54.1, RV4.5
unnamed: R56.2, R64.2, U12.1
unnamed: R58.2, R66.2, U12.7
unnamed: R59.1, RV5.2
unnamed: R60.1, RV5.5
unnamed: R61.2, RV6.2
unnamed: R62.2, RV6.5
unnamed: SW2.1 (A), SW2.4 (A)
unnamed: C34.1, R45.1, SW2.3 (C)
unnamed: R53.1, SW2.6 (C), U11.6 (-), U11.7
unnamed: SW2.7 (A), SW2.10 (A)
unnamed: C33.1, R43.1, SW2.9 (C)
unnamed: R51.1, SW2.12 (C), U11.1, U11.2 (-)
unnamed: C37.1, R47.2, U11.3 (+)
unnamed: C38.1, R48.2, U11.5 (+)
unnamed: R59.2, R61.1, U12.2 (-)
unnamed: R60.2, R62.1, U12.6 (-)

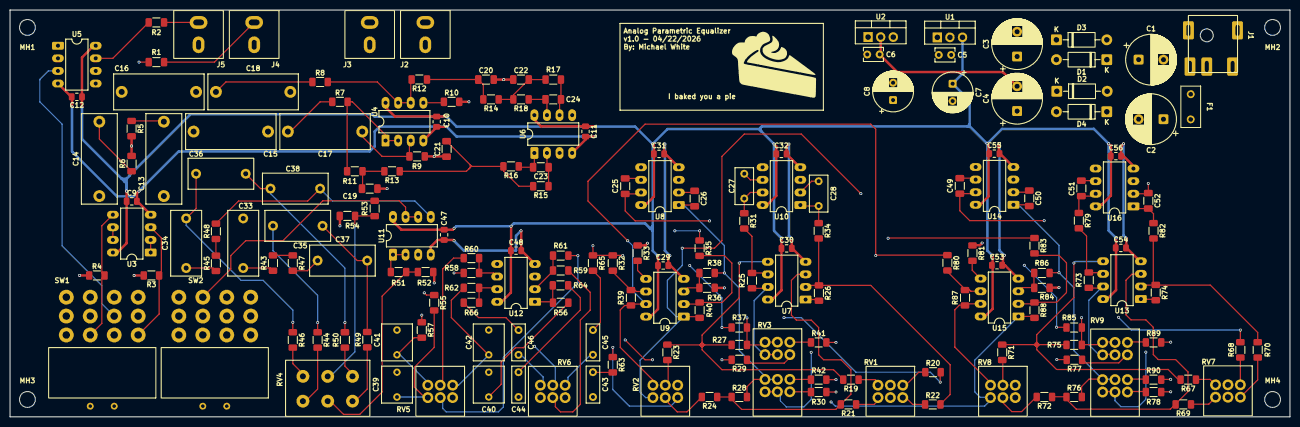
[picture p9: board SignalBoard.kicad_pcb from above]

Board: 4 copper layers, 258.0 x 82.0 mm, 187 parts (0 on the bottom side), 143 nets.

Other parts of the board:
MH1, MH2, MH3, MH4: MountingHole_3.2mm_M3_ISO7380

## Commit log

2026-03-13 LTspice schematics for LPF, HPF, bell, and shelving filters
2026-03-27 Improved filters and added notes
2026-04-17 Updated file structure, readme, add KiCad schematics with real components and notes
    [input_and_bpf.kicad_sch, middle_controls_1.kicad_sch, middle_controls_2_and_output.kicad_sch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]
2026-04-26 Update simulation, routed pcb design, etc. Working on v1.2
    [PowerModule.kicad_pcb, PowerModule.kicad_sch, SignalBoard.csv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]
